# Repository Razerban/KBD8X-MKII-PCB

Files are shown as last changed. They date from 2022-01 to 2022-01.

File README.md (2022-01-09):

# KBD8X-MKII-PCB
This is a portable version of the [KBD8X MKII Project open sourced by Ai03](https://github.com/ai03-2725/KBD8X-MKII-PCB) used in the [KBD8X MKII by KBDfans](https://kbdfans.com/collections/kbd8x-mkii/products/coming-soon-kbd8x-mkii-custom-mechanical-keyboard-kit).

Please verify the conditions of the [license](https://github.com/ai03-2725/KBD8X-MKII-PCB/blob/master/LICENSE) before using.

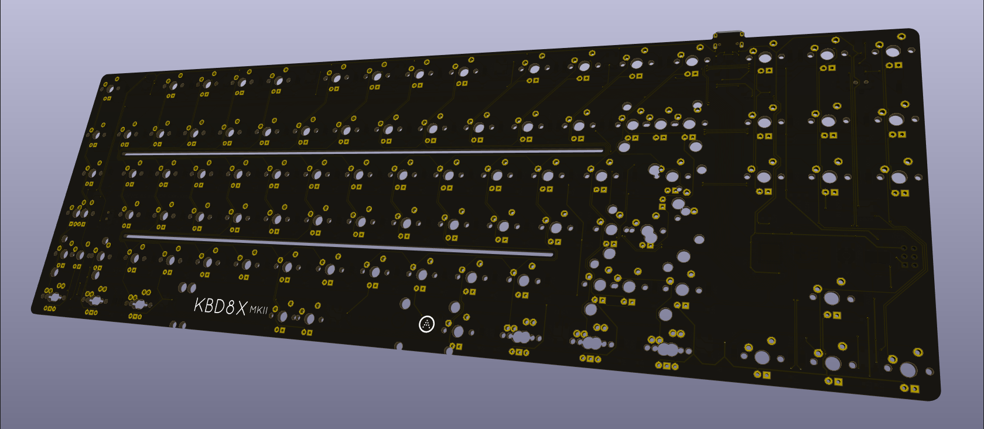
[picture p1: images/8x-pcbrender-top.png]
render

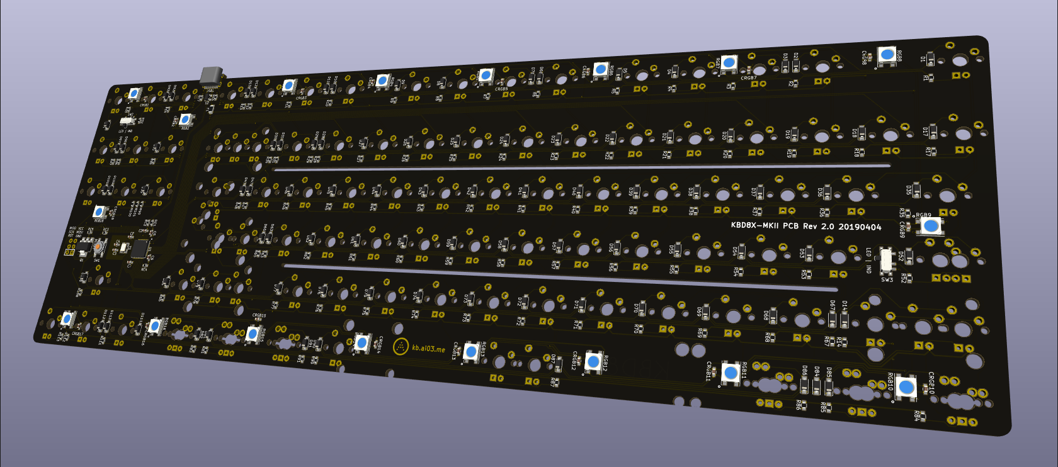
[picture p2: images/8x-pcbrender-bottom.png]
render


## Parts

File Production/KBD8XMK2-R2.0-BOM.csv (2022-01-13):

Comment | Designator | Footprint | LCSC
Crystal 3225 3.2x2.5mm 16MHz | Y1 | Crystal_SMD_3225-4pin_3.2x2.5mm | C13738
Capacitor Ceramic 0603 ≥15V 0.1uF | C6,C7,C8,CRGB1,CRGB10,CRGB11,CRGB12,CRGB13,CRGB14,CRGB15,CRGB16,CRGB17,CRGB18,CRGB2,CRGB3,CRGB4,CRGB5,CRGB6,CRGB7,CRGB8,CRGB9 | C_0603 | C14663
NPN transistor DSS60601MZ4-13 | Q1 | SOT-223-3_TabPin2 | C150451
Capacitor Ceramic 0603 ≥15V 1uF | C2 | C_0603 | C15849
Capacitor Ceramic 0603 ≥15V 22pF | C3,C4 | C_0603 | C1653
USB Type-C Connector HRO-TYPE-C-31-M-12 | USB1 | HRO-TYPE-C-31-M-12-Assembly | C165948
Resistor 0603 1k | R1,R10,R100,R101,R108,R11,R111,R112,R113,R12,R13,R14,R16,R17,R18,R19,R2,R20,R21,R22,R23,R24,R25,R26,R27,R28,R29,R3,R30,R31,R32,R33,R35,R36,R37,R38,R39,R4,R40,R41,R42,R43,R44,R45,R46,R47,R48,R5,R52,R53,R54,R55,R56,R57,R58,R59,R6,R60,R61,R62,R63,R65,R66,R67,R68,R69,R7,R70,R71,R72,R73,R74,R75,R76,R77,R78,R8,R81,R82,R84,R85,R86,R87,R9,R90,R91,R95,R96,R97,R99,RC4 | R_0603 | C21190
Diode SOD-323 | D1,D10,D100,D101,D108,D11,D111,D112,D113,D12,D13,D14,D17,D18,D19,D2,D20,D21,D22,D23,D24,D25,D26,D27,D28,D29,D3,D30,D31,D35,D36,D37,D38,D39,D4,D40,D41,D42,D43,D44,D45,D46,D47,D48,D5,D52,D53,D54,D55,D56,D57,D58,D59,D6,D60,D61,D62,D63,D65,D66,D67,D68,D69,D7,D70,D71,D72,D73,D74,D75,D76,D77,D78,D8,D81,D82,D84,D85,D86,D87,D9,D90,D91,D92,D93,D94,D95,D96,D97,D99 | D_SOD-123 | C2128
Switch SPDT PCM12 | SW2,SW3 | SW_SPDT_PCM12 | C221841
Resistor 0603 1.5k | RC5 | R_0603 | C22843
Resistor 0603 22 | RC1,RC2 | R_0603 | C23345
Resistor 0603 5k1 | RC6,RC7 | R_0603 | C23186
Resistor 0603 10k | RC3 | R_0603 | C25804
Polyfuse 1206 500mA Hold 1A Trip ≥15V | F1 | Fuse_SMD1206_Wave | C261952
RGB LED WS2812B 5050 | RGB1,RGB10,RGB11,RGB12,RGB13,RGB14,RGB15,RGB16,RGB17,RGB18,RGB2,RGB3,RGB4,RGB5,RGB6,RGB7,RGB8,RGB9 | LED_WS2812B-PLCC4 | C2761795
ESD Protection IC PRTR5V0U2X 215 | U2 | SOT143B | C2827688
Push button 5.2 x 5.2mm | SW1 | SKQG-1155865 | C318884
Microship ATmega32U4-MU | U1 | QFN-44-1EP_7x7mm_Pitch0.5mm | C45874
Capacitor Ceramic 0603 ≥15V 10uF | C5 | C_0603 | C96446

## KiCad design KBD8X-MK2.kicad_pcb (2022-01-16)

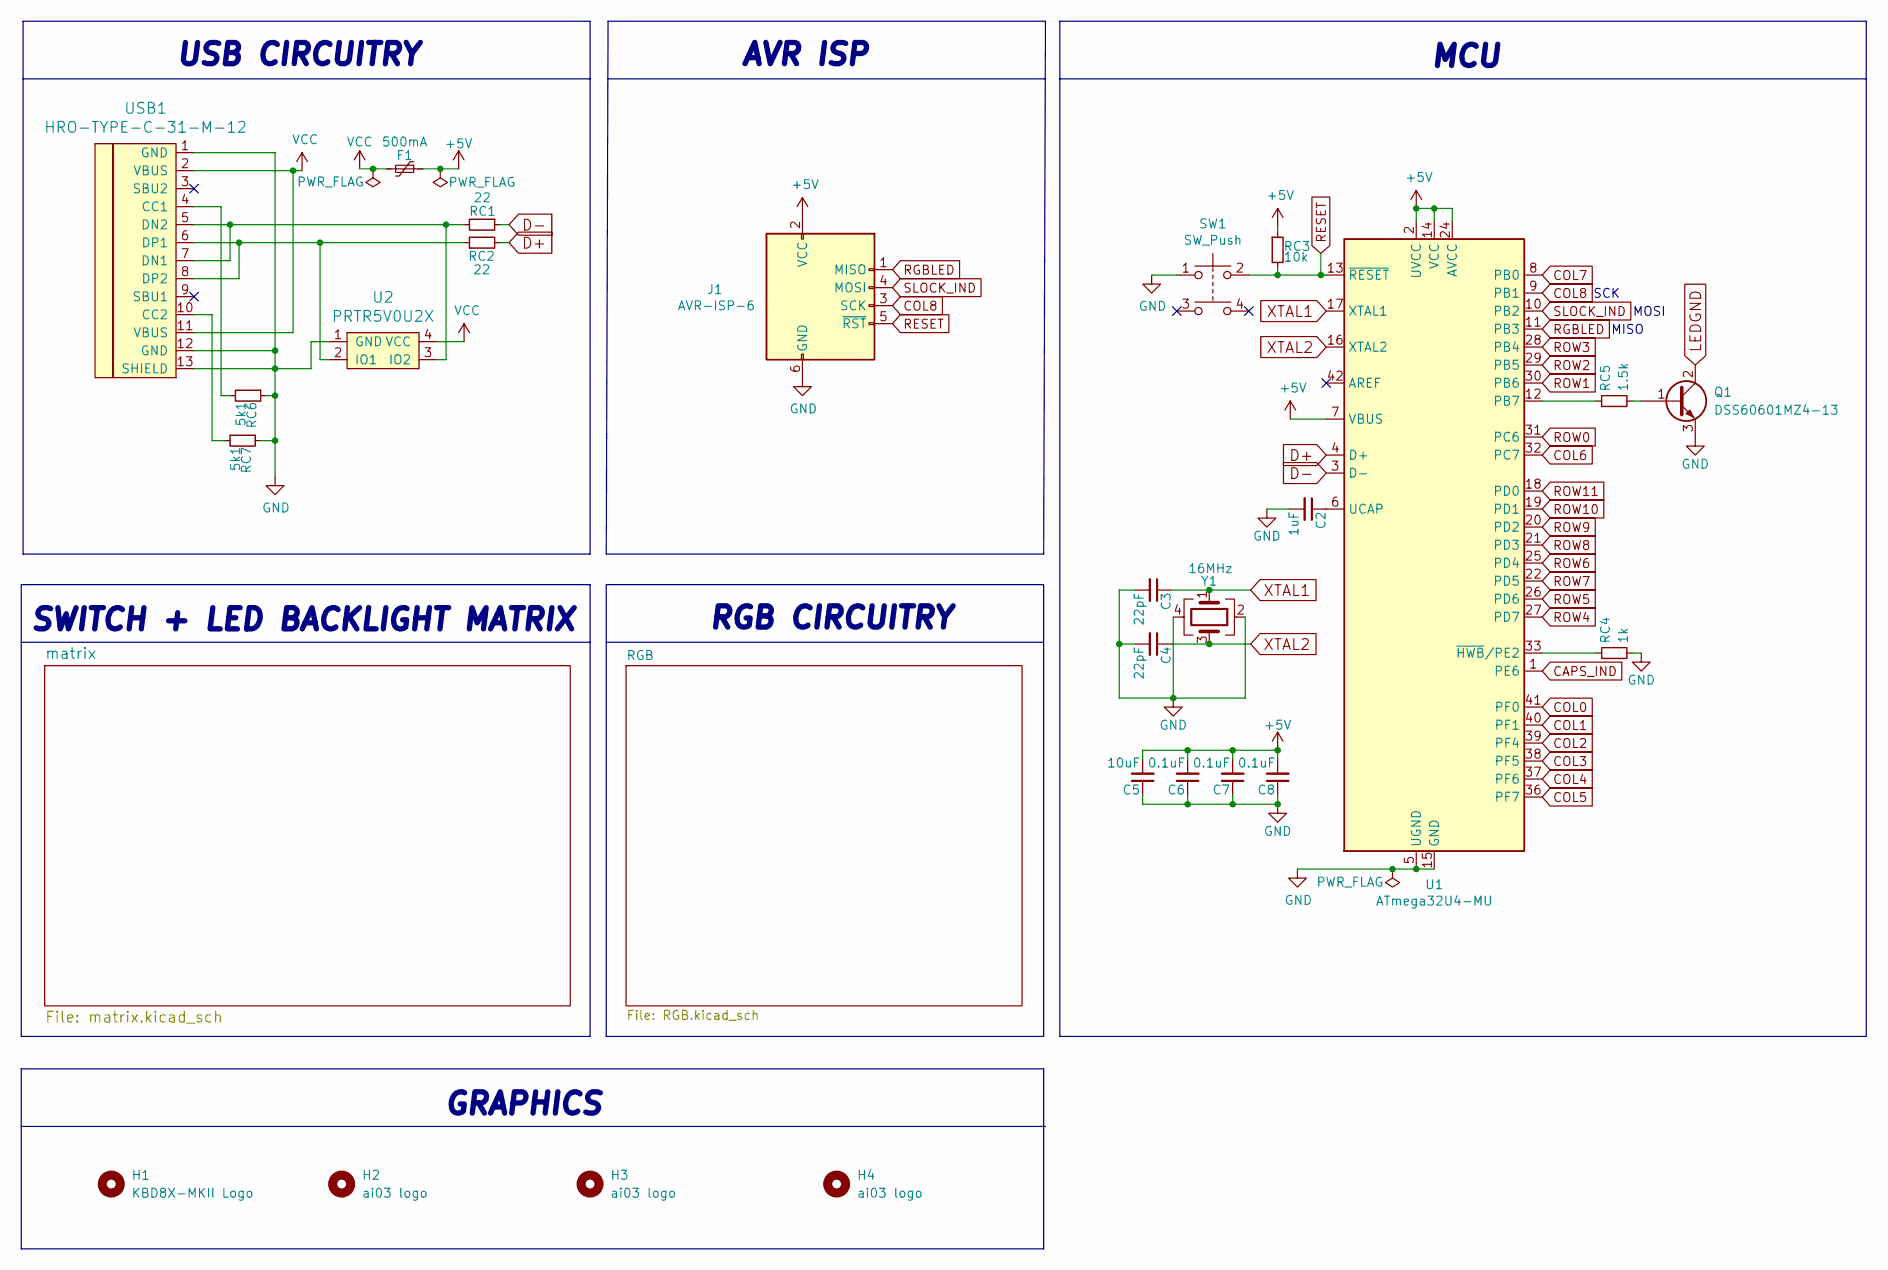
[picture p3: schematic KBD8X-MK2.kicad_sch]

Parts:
C2: 1uF; C_0603
C3, C4: 22pF; C_0603
C5: 10uF; C_0603
C6, C7, C8: 0.1uF; C_0603
F1: 500mA; Fuse_1206_3216Metric
H1: KBD8X-MKII Logo; kbd8x-logo
H2: ai03 logo; ai-ring-6mm-FancyAss
H3: ai03 logo; ai-ring-6mm-FancyAss-Mask
H4: ai03 logo; ai-ring-6mm
J1: AVR-ISP-6; Reset_Pretty-Mask
Q1: DSS60601MZ4-13; SOT-223-3_TabPin2
RC1, RC2: 22; R_0603
RC3: 10k; R_0603
RC4: 1k; R_0603
RC5: 1.5k; R_0603
RC6, RC7: 5k1; R_0603
SW1: SW_Push; SKQG-1155865
U1: ATmega32U4-MU; QFN-44-1EP_7x7mm_P0.5mm_EP5.2x5.2mm
U2: PRTR5V0U2X; SOT143B
USB1: HRO-TYPE-C-31-M-12; HRO-TYPE-C-31-M-12-Assembly
Y1: 16MHz; Crystal_SMD_3225-4pin_3.2x2.5mm

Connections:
+5V: C5.2, C6.2, C7.2, C8.2, F1.1, J1.2 (VCC), RC3.1, U1.2 (UVCC), U1.7 (VBUS), U1.14 (VCC), U1.24 (AVCC), U1.34 (VCC), U1.44 (AVCC); also elsewhere on the board
CAPS_IND: U1.1 (PE6); also elsewhere on the board
COL0: U1.41 (PF0); also elsewhere on the board
COL1: U1.40 (PF1); also elsewhere on the board
COL2: U1.39 (PF4); also elsewhere on the board
COL3: U1.38 (PF5); also elsewhere on the board
COL4: U1.37 (PF6); also elsewhere on the board
COL5: U1.36 (PF7); also elsewhere on the board
COL6: U1.32 (PC7); also elsewhere on the board
COL7: U1.8 (PB0); also elsewhere on the board
COL8: J1.3 (SCK), U1.9 (PB1); also elsewhere on the board
D+: RC2.2, U1.4 (D+)
D-: RC1.1, U1.3 (D-)
GND: C2.2, C3.2, C4.2, C5.1, C6.1, C7.1, C8.1, J1.6 (GND), Q1.3 (E), RC4.2, RC6.1, RC7.1, SW1.1, U1.5 (UGND), U1.15 (GND), U1.23 (GND), U1.35 (GND), U1.43 (GND), U1.45 (GND), U2.1 (GND), USB1.1 (GND), USB1.12 (GND), USB1.13 (SHIELD), Y1.2, Y1.4; also elsewhere on the board
LEDGND: Q1.2 (C); also elsewhere on the board
unnamed: C2.1, U1.6 (UCAP)
unnamed: Q1.1 (B), RC5.2
unnamed: RC1.2, U2.3 (IO2), USB1.5 (DN2), USB1.7 (DN1)
unnamed: RC2.1, U2.2 (IO1), USB1.6 (DP1), USB1.8 (DP2)
unnamed: RC4.1, U1.33 (~HWB/PE2)
unnamed: RC5.1, U1.12 (PB7)
unnamed: RC6.2, USB1.4 (CC1)
unnamed: RC7.2, USB1.10 (CC2)
RESET: J1.5 (~RST), RC3.2, SW1.2, U1.13 (~RESET)
RGBLED: J1.1 (MISO), U1.11 (PB3); also elsewhere on the board
ROW0: U1.31 (PC6); also elsewhere on the board
ROW1: U1.30 (PB6); also elsewhere on the board
ROW2: U1.29 (PB5); also elsewhere on the board
ROW3: U1.28 (PB4); also elsewhere on the board
ROW4: U1.27 (PD7); also elsewhere on the board
ROW5: U1.26 (PD6); also elsewhere on the board
ROW6: U1.25 (PD4); also elsewhere on the board
ROW7: U1.22 (PD5); also elsewhere on the board
ROW8: U1.21 (PD3); also elsewhere on the board
ROW9: U1.20 (PD2); also elsewhere on the board
ROW10: U1.19 (PD1); also elsewhere on the board
ROW11: U1.18 (PD0); also elsewhere on the board
SLOCK_IND: J1.4 (MOSI), U1.10 (PB2); also elsewhere on the board
VCC: F1.2, U2.4 (VCC), USB1.2 (VBUS), USB1.11 (VBUS)
XTAL1: C3.1, U1.17 (XTAL1), Y1.1
XTAL2: C4.1, U1.16 (XTAL2), Y1.3

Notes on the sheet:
SCK
MCU
RGB CIRCUITRY
USB CIRCUITRY
GRAPHICS
AVR ISP
MOSI
SWITCH + LED BACKLIGHT MATRIX
MISO

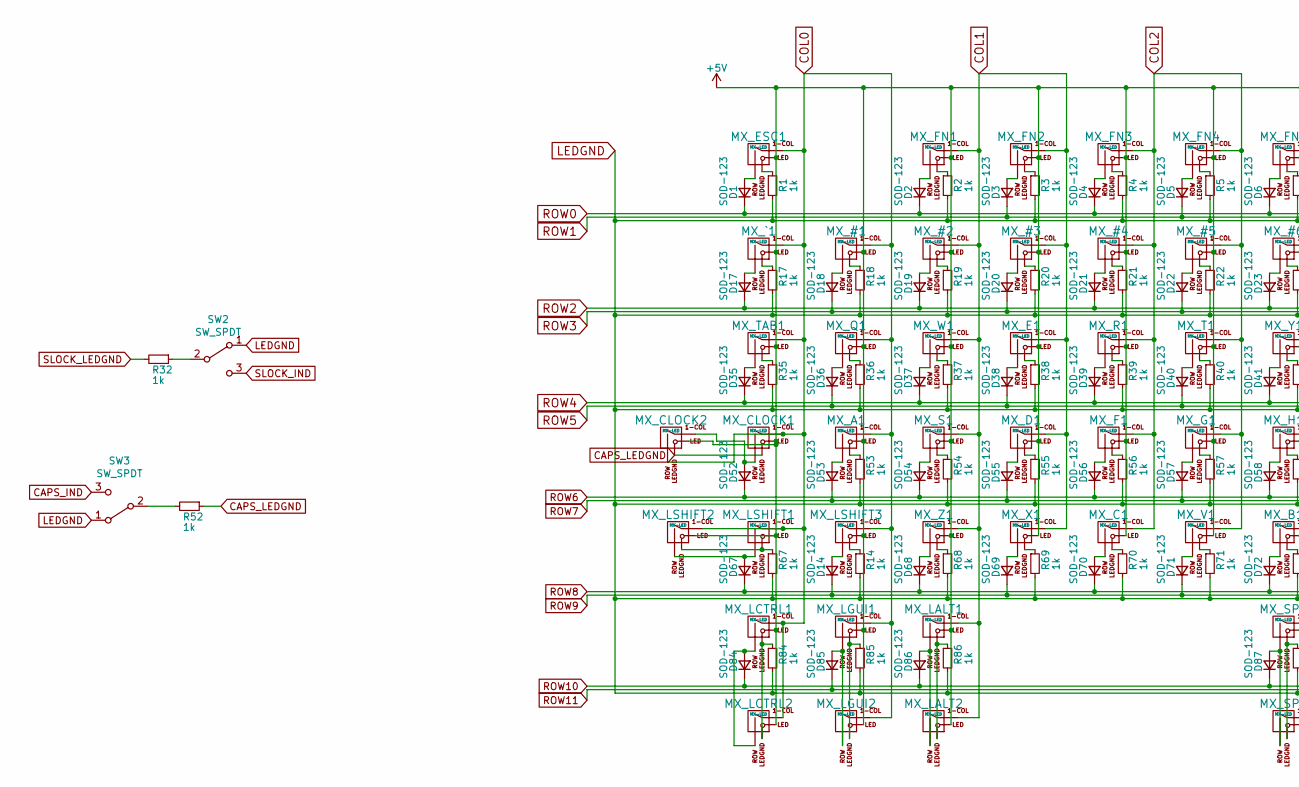
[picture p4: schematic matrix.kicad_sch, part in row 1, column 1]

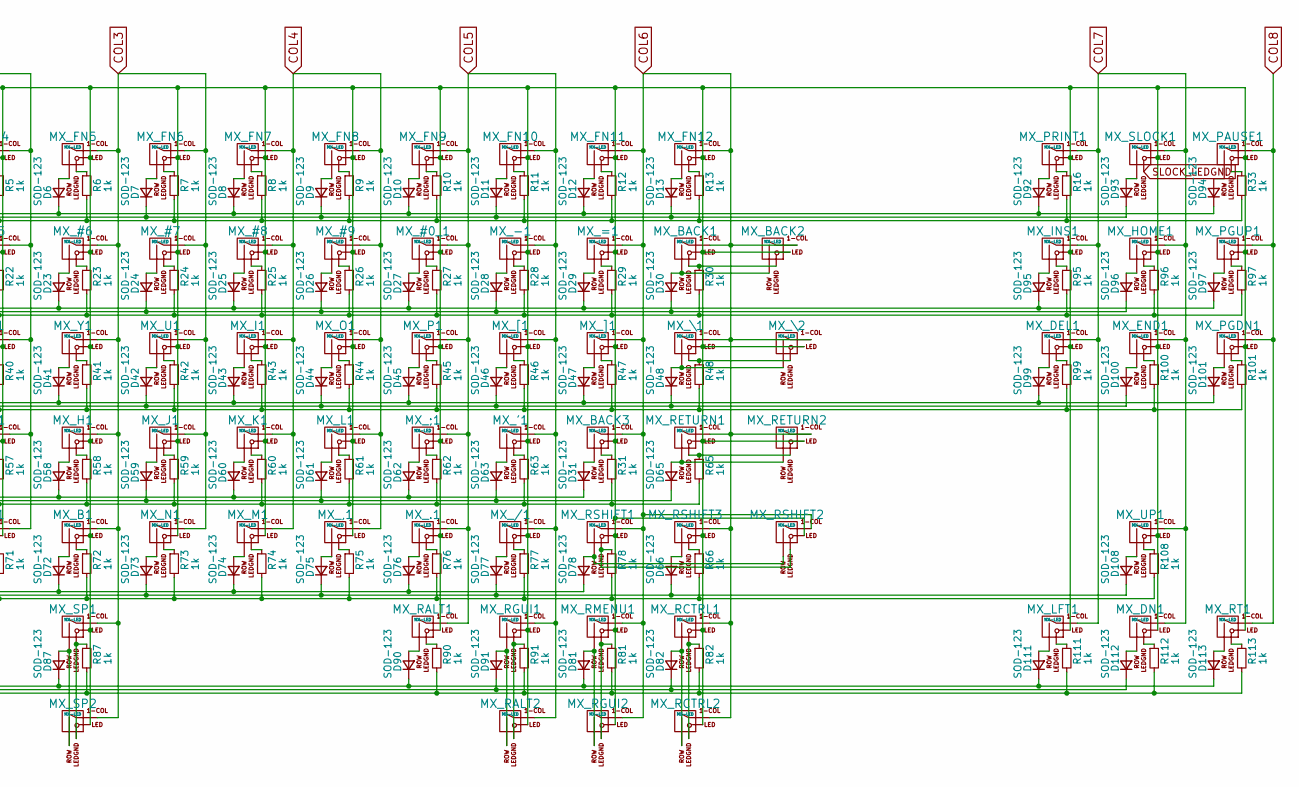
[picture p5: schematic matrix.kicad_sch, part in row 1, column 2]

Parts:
D1, D2, D3, D4, D5, D6, D7, D8, D9, D10, D11, D12, D13, D14, D17, D18, D19, D20, D21, D22, D23, D24, D25, D26, D27, D28, D29, D30, D31, D35, D36, D37, D38, D39, D40, D41, D42, D43, D44, D45, D46, D47, D48, D52, D53, D54, D55, D56, D57, D58, D59, D60, D61, D62, D63, D65, D66, D67, D68, D69, D70, D71, D72, D73, D74, D75, D76, D77, D78, D81, D82, D84, D85, D86, D87, D90, D91, D92, D93, D94, D95, D96, D97, D99, D100, D101, D108, D111, D112, D113: SOD-123; D_SOD-123
MX_#0_1, MX_#1, MX_#2, MX_#3, MX_#4, MX_#5, MX_#6, MX_#7, MX_#8, MX_#9: MX-LED; MXOnly-1U
MX_'1: MX-LED; MXOnly-1U
MX_,1: MX-LED; MXOnly-1U
MX_-1: MX-LED; MXOnly-1U
MX_.1: MX-LED; MXOnly-1U
MX_/1: MX-LED; MXOnly-1U
MX_;1: MX-LED; MXOnly-1U
MX_=1: MX-LED; MXOnly-1U
MX_A1: MX-LED; MXOnly-1U
MX_B1: MX-LED; MXOnly-1U
MX_BACK1: MX-LED; MXOnly-2U
MX_BACK2, MX_BACK3: MX-LED; MXOnly-1U
MX_C1: MX-LED; MXOnly-1U
MX_CLOCK1: MX-LED; MXOnly-1.75U
MX_CLOCK2: MX-LED; MXOnly-1.25U-FLIPPED
MX_D1: MX-LED; MXOnly-1U
MX_DEL1: MX-LED; MXOnly-1U
MX_DN1: MX-LED; MXOnly-1U
MX_E1: MX-LED; MXOnly-1U
MX_END1: MX-LED; MXOnly-1U
MX_ESC1: MX-LED; MXOnly-1U
MX_F1: MX-LED; MXOnly-1U
MX_FN1, MX_FN2, MX_FN3, MX_FN4, MX_FN5, MX_FN6, MX_FN7, MX_FN8, MX_FN9, MX_FN10, MX_FN11, MX_FN12: MX-LED; MXOnly-1U
MX_G1: MX-LED; MXOnly-1U
MX_H1: MX-LED; MXOnly-1U
MX_HOME1: MX-LED; MXOnly-1U
MX_I1: MX-LED; MXOnly-1U
MX_INS1: MX-LED; MXOnly-1U
MX_J1: MX-LED; MXOnly-1U
MX_K1: MX-LED; MXOnly-1U
MX_L1: MX-LED; MXOnly-1U
MX_LALT1: MX-LED; MXOnly-1.25U
MX_LALT2: MX-LED; MXOnly-1.5U-FLIPPED
MX_LCTRL1: MX-LED; MXOnly-1.25U
MX_LCTRL2: MX-LED; MXOnly-1.5U-FLIPPED
MX_LFT1: MX-LED; MXOnly-1U
MX_LGUI1: MX-LED; MXOnly-1.25U
MX_LGUI2: MX-LED; MXOnly-1U-FLIPPED
MX_LSHIFT1: MX-LED; MXOnly-2.25U
MX_LSHIFT2: MX-LED; MXOnly-1.25U
MX_LSHIFT3: MX-LED; MXOnly-1U
MX_M1: MX-LED; MXOnly-1U
MX_N1: MX-LED; MXOnly-1U
MX_O1: MX-LED; MXOnly-1U
MX_P1: MX-LED; MXOnly-1U
MX_PAUSE1: MX-LED; MXOnly-1U
MX_PGDN1: MX-LED; MXOnly-1U
MX_PGUP1: MX-LED; MXOnly-1U
MX_PRINT1: MX-LED; MXOnly-1U
MX_Q1: MX-LED; MXOnly-1U
MX_R1: MX-LED; MXOnly-1U
MX_RALT1: MX-LED; MXOnly-1.25U
MX_RALT2: MX-LED; MXOnly-1.5U
MX_RCTRL1: MX-LED; MXOnly-1.25U-FLIPPED
MX_RCTRL2: MX-LED; MXOnly-1.5U
MX_RETURN1: MX-LED; MXOnly-2.25U
MX_RETURN2: MX-LED; MXOnly-ISO-ROTATED-ReversedStabilizers
MX_RGUI1: MX-LED; MXOnly-1.25U-FLIPPED
MX_RGUI2: MX-LED; MXOnly-1U
MX_RMENU1: MX-LED; MXOnly-1.25U-FLIPPED
MX_RSHIFT1: MX-LED; MXOnly-2.75U
MX_RSHIFT2: MX-LED; MXOnly-1.75U
MX_RSHIFT3: MX-LED; MXOnly-1U
MX_RT1: MX-LED; MXOnly-1U
MX_S1: MX-LED; MXOnly-1U
MX_SLOCK1: MX-LED; MXOnly-1U
MX_SP1: MX-LED; MXOnly-6.25U-ReversedStabilizers
MX_SP2: MX-LED; MXOnly-7U-ReversedStabilizers
MX_T1: MX-LED; MXOnly-1U
MX_TAB1: MX-LED; MXOnly-1.5U
MX_U1: MX-LED; MXOnly-1U
MX_UP1: MX-LED; MXOnly-1U
MX_V1: MX-LED; MXOnly-1U
MX_W1: MX-LED; MXOnly-1U
MX_X1: MX-LED; MXOnly-1U
MX_Y1: MX-LED; MXOnly-1U
MX_Z1: MX-LED; MXOnly-1U
MX_[1: MX-LED; MXOnly-1U
MX_\1: MX-LED; MXOnly-1.5U
MX_\2: MX-LED; MXOnly-1U
MX_]1: MX-LED; MXOnly-1U
MX_`1: MX-LED; MXOnly-1U
R1, R2, R3, R4, R5, R6, R7, R8, R9, R10, R11, R12, R13, R14, R16, R17, R18, R19, R20, R21, R22, R23, R24, R25, R26, R27, R28, R29, R30, R31, R32, R33, R35, R36, R37, R38, R39, R40, R41, R42, R43, R44, R45, R46, R47, R48, R52, R53, R54, R55, R56, R57, R58, R59, R60, R61, R62, R63, R65, R66, R67, R68, R69, R70, R71, R72, R73, R74, R75, R76, R77, R78, R81, R82, R84, R85, R86, R87, R90, R91, R95, R96, R97, R99, R100, R101, R108, R111, R112, R113: 1k; R_0603
SW2, SW3: SW_SPDT; SW_SPDT_PCM12

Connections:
+5V: MX_#0_1.3 (LED), MX_#1.3 (LED), MX_#2.3 (LED), MX_#3.3 (LED), MX_#4.3 (LED), MX_#5.3 (LED), MX_#6.3 (LED), MX_#7.3 (LED), MX_#8.3 (LED), MX_#9.3 (LED), MX_'1.3 (LED), MX_,1.3 (LED), MX_-1.3 (LED), MX_.1.3 (LED), MX_/1.3 (LED), MX_;1.3 (LED), MX_=1.3 (LED), MX_A1.3 (LED), MX_B1.3 (LED), MX_BACK1.3 (LED), MX_BACK2.3 (LED), MX_BACK3.3 (LED), MX_C1.3 (LED), MX_CLOCK1.3 (LED), MX_CLOCK2.3 (LED), MX_D1.3 (LED), MX_DEL1.3 (LED), MX_DN1.3 (LED), MX_E1.3 (LED), MX_END1.3 (LED), MX_ESC1.3 (LED), MX_F1.3 (LED), MX_FN1.3 (LED), MX_FN2.3 (LED), MX_FN3.3 (LED), MX_FN4.3 (LED), MX_FN5.3 (LED), MX_FN6.3 (LED), MX_FN7.3 (LED), MX_FN8.3 (LED), MX_FN9.3 (LED), MX_FN10.3 (LED), MX_FN11.3 (LED), MX_FN12.3 (LED), MX_G1.3 (LED), MX_H1.3 (LED), MX_HOME1.3 (LED), MX_I1.3 (LED), MX_INS1.3 (LED), MX_J1.3 (LED), MX_K1.3 (LED), MX_L1.3 (LED), MX_LALT1.3 (LED), MX_LALT2.3 (LED), MX_LCTRL1.3 (LED), MX_LCTRL2.3 (LED), MX_LFT1.3 (LED), MX_LGUI1.3 (LED), MX_LGUI2.3 (LED), MX_LSHIFT1.3 (LED), MX_LSHIFT2.3 (LED), MX_LSHIFT3.3 (LED), MX_M1.3 (LED), MX_N1.3 (LED), MX_O1.3 (LED), MX_P1.3 (LED), MX_PAUSE1.3 (LED), MX_PGDN1.3 (LED), MX_PGUP1.3 (LED), MX_PRINT1.3 (LED), MX_Q1.3 (LED), MX_R1.3 (LED), MX_RALT1.3 (LED), MX_RALT2.3 (LED), MX_RCTRL1.3 (LED), MX_RCTRL2.3 (LED), MX_RETURN1.3 (LED), MX_RETURN2.3 (LED), MX_RGUI1.3 (LED), MX_RGUI2.3 (LED), MX_RMENU1.3 (LED), MX_RSHIFT1.3 (LED), MX_RSHIFT2.3 (LED), MX_RSHIFT3.3 (LED), MX_RT1.3 (LED), MX_S1.3 (LED), MX_SLOCK1.3 (LED), MX_SP1.3 (LED), MX_SP2.3 (LED), MX_T1.3 (LED), MX_TAB1.3 (LED), MX_U1.3 (LED), MX_UP1.3 (LED), MX_V1.3 (LED), MX_W1.3 (LED), MX_X1.3 (LED), MX_Y1.3 (LED), MX_Z1.3 (LED), MX_[1.3 (LED), MX_\1.3 (LED), MX_\2.3 (LED), MX_]1.3 (LED), MX_`1.3 (LED); also elsewhere on the board
CAPS_IND: SW3.3 (C); also elsewhere on the board
CAPS_LEDGND: MX_CLOCK1.4 (LEDGND), MX_CLOCK2.4 (LEDGND), R52.1
COL0: MX_#1.1 (COL), MX_A1.1 (COL), MX_CLOCK1.1 (COL), MX_CLOCK2.2 (ROW), MX_ESC1.1 (COL), MX_LCTRL1.1 (COL), MX_LCTRL2.1 (COL), MX_LGUI1.1 (COL), MX_LGUI2.1 (COL), MX_LSHIFT1.1 (COL), MX_LSHIFT2.1 (COL), MX_LSHIFT3.1 (COL), MX_Q1.1 (COL), MX_TAB1.1 (COL), MX_`1.1 (COL); also elsewhere on the board
COL1: MX_#2.1 (COL), MX_#3.1 (COL), MX_D1.1 (COL), MX_E1.1 (COL), MX_FN1.1 (COL), MX_FN2.1 (COL), MX_LALT1.1 (COL), MX_LALT2.1 (COL), MX_S1.1 (COL), MX_W1.1 (COL), MX_X1.1 (COL), MX_Z1.1 (COL); also elsewhere on the board
COL2: MX_#4.1 (COL), MX_#5.1 (COL), MX_C1.1 (COL), MX_F1.1 (COL), MX_FN3.1 (COL), MX_FN4.1 (COL), MX_G1.1 (COL), MX_R1.1 (COL), MX_T1.1 (COL), MX_V1.1 (COL); also elsewhere on the board
COL3: MX_#6.1 (COL), MX_#7.1 (COL), MX_B1.1 (COL), MX_FN5.1 (COL), MX_FN6.1 (COL), MX_H1.1 (COL), MX_J1.1 (COL), MX_N1.1 (COL), MX_SP1.1 (COL), MX_SP2.1 (COL), MX_U1.1 (COL), MX_Y1.1 (COL); also elsewhere on the board
COL4: MX_#8.1 (COL), MX_#9.1 (COL), MX_,1.1 (COL), MX_FN7.1 (COL), MX_FN8.1 (COL), MX_I1.1 (COL), MX_K1.1 (COL), MX_L1.1 (COL), MX_M1.1 (COL), MX_O1.1 (COL); also elsewhere on the board
COL5: MX_#0_1.1 (COL), MX_'1.1 (COL), MX_-1.1 (COL), MX_.1.1 (COL), MX_/1.1 (COL), MX_;1.1 (COL), MX_FN9.1 (COL), MX_FN10.1 (COL), MX_P1.1 (COL), MX_RALT1.1 (COL), MX_RALT2.1 (COL), MX_RGUI1.1 (COL), MX_[1.1 (COL); also elsewhere on the board
COL6: MX_=1.1 (COL), MX_BACK1.1 (COL), MX_BACK2.1 (COL), MX_BACK3.1 (COL), MX_FN11.1 (COL), MX_FN12.1 (COL), MX_RCTRL1.1 (COL), MX_RCTRL2.1 (COL), MX_RETURN1.1 (COL), MX_RETURN2.1 (COL), MX_RGUI2.1 (COL), MX_RMENU1.1 (COL), MX_RSHIFT1.1 (COL), MX_RSHIFT2.1 (COL), MX_RSHIFT3.1 (COL), MX_\1.1 (COL), MX_\2.1 (COL), MX_]1.1 (COL); also elsewhere on the board
COL7: MX_DEL1.1 (COL), MX_DN1.1 (COL), MX_END1.1 (COL), MX_HOME1.1 (COL), MX_INS1.1 (COL), MX_LFT1.1 (COL), MX_PRINT1.1 (COL), MX_SLOCK1.1 (COL), MX_UP1.1 (COL); also elsewhere on the board
COL8: MX_PAUSE1.1 (COL), MX_PGDN1.1 (COL), MX_PGUP1.1 (COL), MX_RT1.1 (COL); also elsewhere on the board
LEDGND: R1.2, R2.2, R3.2, R4.2, R5.2, R6.2, R7.2, R8.2, R9.2, R10.2, R11.2, R12.2, R13.2, R14.2, R16.2, R17.2, R18.2, R19.2, R20.2, R21.2, R22.2, R23.2, R24.2, R25.2, R26.2, R27.2, R28.2, R29.2, R30.2, R31.2, R33.2, R35.2, R36.2, R37.2, R38.2, R39.2, R40.2, R41.2, R42.2, R43.2, R44.2, R45.2, R46.2, R47.2, R48.2, R53.2, R54.2, R55.2, R56.2, R57.2, R58.2, R59.2, R60.2, R61.2, R62.2, R63.2, R65.2, R66.2, R67.2, R68.2, R69.2, R70.2, R71.2, R72.2, R73.2, R74.2, R75.2, R76.2, R77.2, R78.2, R81.2, R82.2, R84.2, R85.2, R86.2, R87.2, R90.2, R91.2, R95.2, R96.2, R97.2, R99.2, R100.2, R101.2, R108.2, R111.2, R112.2, R113.2, SW2.1 (A), SW3.1 (A); also elsewhere on the board
unnamed: D1.2 (A), MX_ESC1.2 (ROW)
unnamed: D2.2 (A), MX_FN1.2 (ROW)
unnamed: D3.2 (A), MX_FN2.2 (ROW)
unnamed: D4.2 (A), MX_FN3.2 (ROW)
unnamed: D5.2 (A), MX_FN4.2 (ROW)
unnamed: D6.2 (A), MX_FN5.2 (ROW)
unnamed: D7.2 (A), MX_FN6.2 (ROW)
unnamed: D8.2 (A), MX_FN7.2 (ROW)
unnamed: D9.2 (A), MX_FN8.2 (ROW)
unnamed: D10.2 (A), MX_FN9.2 (ROW)
unnamed: D11.2 (A), MX_FN10.2 (ROW)
unnamed: D12.2 (A), MX_FN11.2 (ROW)
unnamed: D13.2 (A), MX_FN12.2 (ROW)
unnamed: D14.2 (A), MX_LSHIFT3.2 (ROW)
unnamed: D17.2 (A), MX_`1.2 (ROW)
unnamed: D18.2 (A), MX_#1.2 (ROW)
unnamed: D19.2 (A), MX_#2.2 (ROW)
unnamed: D20.2 (A), MX_#3.2 (ROW)
unnamed: D21.2 (A), MX_#4.2 (ROW)
unnamed: D22.2 (A), MX_#5.2 (ROW)
unnamed: D23.2 (A), MX_#6.2 (ROW)
unnamed: D24.2 (A), MX_#7.2 (ROW)
unnamed: D25.2 (A), MX_#8.2 (ROW)
unnamed: D26.2 (A), MX_#9.2 (ROW)
unnamed: D27.2 (A), MX_#0_1.2 (ROW)
unnamed: D28.2 (A), MX_-1.2 (ROW)
unnamed: D29.2 (A), MX_=1.2 (ROW)
unnamed: D30.2 (A), MX_BACK1.2 (ROW), MX_BACK2.2 (ROW)
unnamed: D31.2 (A), MX_BACK3.2 (ROW)
unnamed: D35.2 (A), MX_TAB1.2 (ROW)
unnamed: D36.2 (A), MX_Q1.2 (ROW)
unnamed: D37.2 (A), MX_W1.2 (ROW)
unnamed: D38.2 (A), MX_E1.2 (ROW)
unnamed: D39.2 (A), MX_R1.2 (ROW)
unnamed: D40.2 (A), MX_T1.2 (ROW)
unnamed: D41.2 (A), MX_Y1.2 (ROW)
unnamed: D42.2 (A), MX_U1.2 (ROW)
unnamed: D43.2 (A), MX_I1.2 (ROW)
unnamed: D44.2 (A), MX_O1.2 (ROW)
unnamed: D45.2 (A), MX_P1.2 (ROW)
unnamed: D46.2 (A), MX_[1.2 (ROW)
unnamed: D47.2 (A), MX_]1.2 (ROW)
unnamed: D48.2 (A), MX_\1.2 (ROW), MX_\2.2 (ROW)
unnamed: D52.2 (A), MX_CLOCK1.2 (ROW), MX_CLOCK2.1 (COL)
unnamed: D53.2 (A), MX_A1.2 (ROW)
unnamed: D54.2 (A), MX_S1.2 (ROW)
unnamed: D55.2 (A), MX_D1.2 (ROW)
unnamed: D56.2 (A), MX_F1.2 (ROW)
unnamed: D57.2 (A), MX_G1.2 (ROW)
unnamed: D58.2 (A), MX_H1.2 (ROW)
unnamed: D59.2 (A), MX_J1.2 (ROW)
unnamed: D60.2 (A), MX_K1.2 (ROW)
unnamed: D61.2 (A), MX_L1.2 (ROW)
unnamed: D62.2 (A), MX_;1.2 (ROW)
unnamed: D63.2 (A), MX_'1.2 (ROW)
unnamed: D65.2 (A), MX_RETURN1.2 (ROW), MX_RETURN2.2 (ROW)
unnamed: D66.2 (A), MX_RSHIFT3.2 (ROW)
unnamed: D67.2 (A), MX_LSHIFT1.2 (ROW), MX_LSHIFT2.2 (ROW)
unnamed: D68.2 (A), MX_Z1.2 (ROW)
unnamed: D69.2 (A), MX_X1.2 (ROW)
unnamed: D70.2 (A), MX_C1.2 (ROW)
unnamed: D71.2 (A), MX_V1.2 (ROW)
unnamed: D72.2 (A), MX_B1.2 (ROW)
unnamed: D73.2 (A), MX_N1.2 (ROW)
unnamed: D74.2 (A), MX_M1.2 (ROW)
unnamed: D75.2 (A), MX_,1.2 (ROW)
unnamed: D76.2 (A), MX_.1.2 (ROW)
unnamed: D77.2 (A), MX_/1.2 (ROW)
unnamed: D78.2 (A), MX_RSHIFT1.2 (ROW), MX_RSHIFT2.2 (ROW)
unnamed: D81.2 (A), MX_RGUI2.2 (ROW), MX_RMENU1.2 (ROW)
unnamed: D82.2 (A), MX_RCTRL1.2 (ROW), MX_RCTRL2.2 (ROW)
unnamed: D84.2 (A), MX_LCTRL1.2 (ROW), MX_LCTRL2.2 (ROW)
unnamed: D85.2 (A), MX_LGUI1.2 (ROW), MX_LGUI2.2 (ROW)
unnamed: D86.2 (A), MX_LALT1.2 (ROW), MX_LALT2.2 (ROW)
unnamed: D87.2 (A), MX_SP1.2 (ROW), MX_SP2.2 (ROW)
unnamed: D90.2 (A), MX_RALT1.2 (ROW)
unnamed: D91.2 (A), MX_RALT2.2 (ROW), MX_RGUI1.2 (ROW)
unnamed: D92.2 (A), MX_PRINT1.2 (ROW)
unnamed: D93.2 (A), MX_SLOCK1.2 (ROW)
unnamed: D94.2 (A), MX_PAUSE1.2 (ROW)
unnamed: D95.2 (A), MX_INS1.2 (ROW)
unnamed: D96.2 (A), MX_HOME1.2 (ROW)
unnamed: D97.2 (A), MX_PGUP1.2 (ROW)
unnamed: D99.2 (A), MX_DEL1.2 (ROW)
unnamed: D100.2 (A), MX_END1.2 (ROW)
unnamed: D101.2 (A), MX_PGDN1.2 (ROW)
unnamed: D108.2 (A), MX_UP1.2 (ROW)
unnamed: D111.2 (A), MX_LFT1.2 (ROW)
unnamed: D112.2 (A), MX_DN1.2 (ROW)
unnamed: D113.2 (A), MX_RT1.2 (ROW)
unnamed: MX_#0_1.4 (LEDGND), R27.1
unnamed: MX_#1.4 (LEDGND), R18.1
unnamed: MX_#2.4 (LEDGND), R19.1
unnamed: MX_#3.4 (LEDGND), R20.1
unnamed: MX_#4.4 (LEDGND), R21.1
unnamed: MX_#5.4 (LEDGND), R22.1
unnamed: MX_#6.4 (LEDGND), R23.1
unnamed: MX_#7.4 (LEDGND), R24.1
unnamed: MX_#8.4 (LEDGND), R25.1
unnamed: MX_#9.4 (LEDGND), R26.1
unnamed: MX_'1.4 (LEDGND), R63.1
unnamed: MX_,1.4 (LEDGND), R75.1
unnamed: MX_-1.4 (LEDGND), R28.1
unnamed: MX_.1.4 (LEDGND), R76.1
unnamed: MX_/1.4 (LEDGND), R77.1
unnamed: MX_;1.4 (LEDGND), R62.1
unnamed: MX_=1.4 (LEDGND), R29.1
unnamed: MX_A1.4 (LEDGND), R53.1
unnamed: MX_B1.4 (LEDGND), R72.1
unnamed: MX_BACK1.4 (LEDGND), MX_BACK2.4 (LEDGND), R30.1
unnamed: MX_BACK3.4 (LEDGND), R31.1
unnamed: MX_C1.4 (LEDGND), R70.1
unnamed: MX_D1.4 (LEDGND), R55.1
unnamed: MX_DEL1.4 (LEDGND), R99.1
unnamed: MX_DN1.4 (LEDGND), R112.1
unnamed: MX_E1.4 (LEDGND), R38.1
unnamed: MX_END1.4 (LEDGND), R100.1
unnamed: MX_ESC1.4 (LEDGND), R1.1
unnamed: MX_F1.4 (LEDGND), R56.1
unnamed: MX_FN1.4 (LEDGND), R2.1
unnamed: MX_FN2.4 (LEDGND), R3.1
unnamed: MX_FN3.4 (LEDGND), R4.1
unnamed: MX_FN4.4 (LEDGND), R5.1
unnamed: MX_FN5.4 (LEDGND), R6.1
unnamed: MX_FN6.4 (LEDGND), R7.1
unnamed: MX_FN7.4 (LEDGND), R8.1
unnamed: MX_FN8.4 (LEDGND), R9.1
unnamed: MX_FN9.4 (LEDGND), R10.1
unnamed: MX_FN10.4 (LEDGND), R11.1
unnamed: MX_FN11.4 (LEDGND), R12.1
unnamed: MX_FN12.4 (LEDGND), R13.1
unnamed: MX_G1.4 (LEDGND), R57.1
unnamed: MX_H1.4 (LEDGND), R58.1
unnamed: MX_HOME1.4 (LEDGND), R96.1
unnamed: MX_I1.4 (LEDGND), R43.1
unnamed: MX_INS1.4 (LEDGND), R95.1
unnamed: MX_J1.4 (LEDGND), R59.1
unnamed: MX_K1.4 (LEDGND), R60.1
unnamed: MX_L1.4 (LEDGND), R61.1
unnamed: MX_LALT1.4 (LEDGND), MX_LALT2.4 (LEDGND), R86.1
unnamed: MX_LCTRL1.4 (LEDGND), MX_LCTRL2.4 (LEDGND), R84.1
unnamed: MX_LFT1.4 (LEDGND), R111.1
unnamed: MX_LGUI1.4 (LEDGND), MX_LGUI2.4 (LEDGND), R85.1
unnamed: MX_LSHIFT1.4 (LEDGND), MX_LSHIFT2.4 (LEDGND), R67.1
unnamed: MX_LSHIFT3.4 (LEDGND), R14.1
unnamed: MX_M1.4 (LEDGND), R74.1
unnamed: MX_N1.4 (LEDGND), R73.1
unnamed: MX_O1.4 (LEDGND), R44.1
unnamed: MX_P1.4 (LEDGND), R45.1
unnamed: MX_PAUSE1.4 (LEDGND), R33.1
unnamed: MX_PGDN1.4 (LEDGND), R101.1
unnamed: MX_PGUP1.4 (LEDGND), R97.1
unnamed: MX_PRINT1.4 (LEDGND), R16.1
unnamed: MX_Q1.4 (LEDGND), R36.1
unnamed: MX_R1.4 (LEDGND), R39.1
unnamed: MX_RALT1.4 (LEDGND), R90.1
unnamed: MX_RALT2.4 (LEDGND), MX_RGUI1.4 (LEDGND), R91.1
unnamed: MX_RCTRL1.4 (LEDGND), MX_RCTRL2.4 (LEDGND), R82.1
unnamed: MX_RETURN1.4 (LEDGND), MX_RETURN2.4 (LEDGND), R65.1
unnamed: MX_RGUI2.4 (LEDGND), MX_RMENU1.4 (LEDGND), R81.1
unnamed: MX_RSHIFT1.4 (LEDGND), MX_RSHIFT2.4 (LEDGND), R78.1
unnamed: MX_RSHIFT3.4 (LEDGND), R66.1
unnamed: MX_RT1.4 (LEDGND), R113.1
unnamed: MX_S1.4 (LEDGND), R54.1
unnamed: MX_SP1.4 (LEDGND), MX_SP2.4 (LEDGND), R87.1
unnamed: MX_T1.4 (LEDGND), R40.1
unnamed: MX_TAB1.4 (LEDGND), R35.1
unnamed: MX_U1.4 (LEDGND), R42.1
unnamed: MX_UP1.4 (LEDGND), R108.1
unnamed: MX_V1.4 (LEDGND), R71.1
unnamed: MX_W1.4 (LEDGND), R37.1
unnamed: MX_X1.4 (LEDGND), R69.1
unnamed: MX_Y1.4 (LEDGND), R41.1
unnamed: MX_Z1.4 (LEDGND), R68.1
unnamed: MX_[1.4 (LEDGND), R46.1
unnamed: MX_\1.4 (LEDGND), MX_\2.4 (LEDGND), R48.1
unnamed: MX_]1.4 (LEDGND), R47.1
unnamed: MX_`1.4 (LEDGND), R17.1
unnamed: R32.1, SW2.2 (B)
unnamed: R52.2, SW3.2 (B)
ROW0: D1.1 (K), D2.1 (K), D4.1 (K), D6.1 (K), D8.1 (K), D10.1 (K), D12.1 (K), D92.1 (K), D94.1 (K); also elsewhere on the board
ROW1: D3.1 (K), D5.1 (K), D7.1 (K), D9.1 (K), D11.1 (K), D13.1 (K), D93.1 (K); also elsewhere on the board
ROW2: D17.1 (K), D19.1 (K), D21.1 (K), D23.1 (K), D25.1 (K), D27.1 (K), D29.1 (K), D95.1 (K), D97.1 (K); also elsewhere on the board
ROW3: D18.1 (K), D20.1 (K), D22.1 (K), D24.1 (K), D26.1 (K), D28.1 (K), D30.1 (K), D96.1 (K); also elsewhere on the board
ROW4: D35.1 (K), D37.1 (K), D39.1 (K), D41.1 (K), D43.1 (K), D45.1 (K), D47.1 (K), D99.1 (K), D101.1 (K); also elsewhere on the board
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

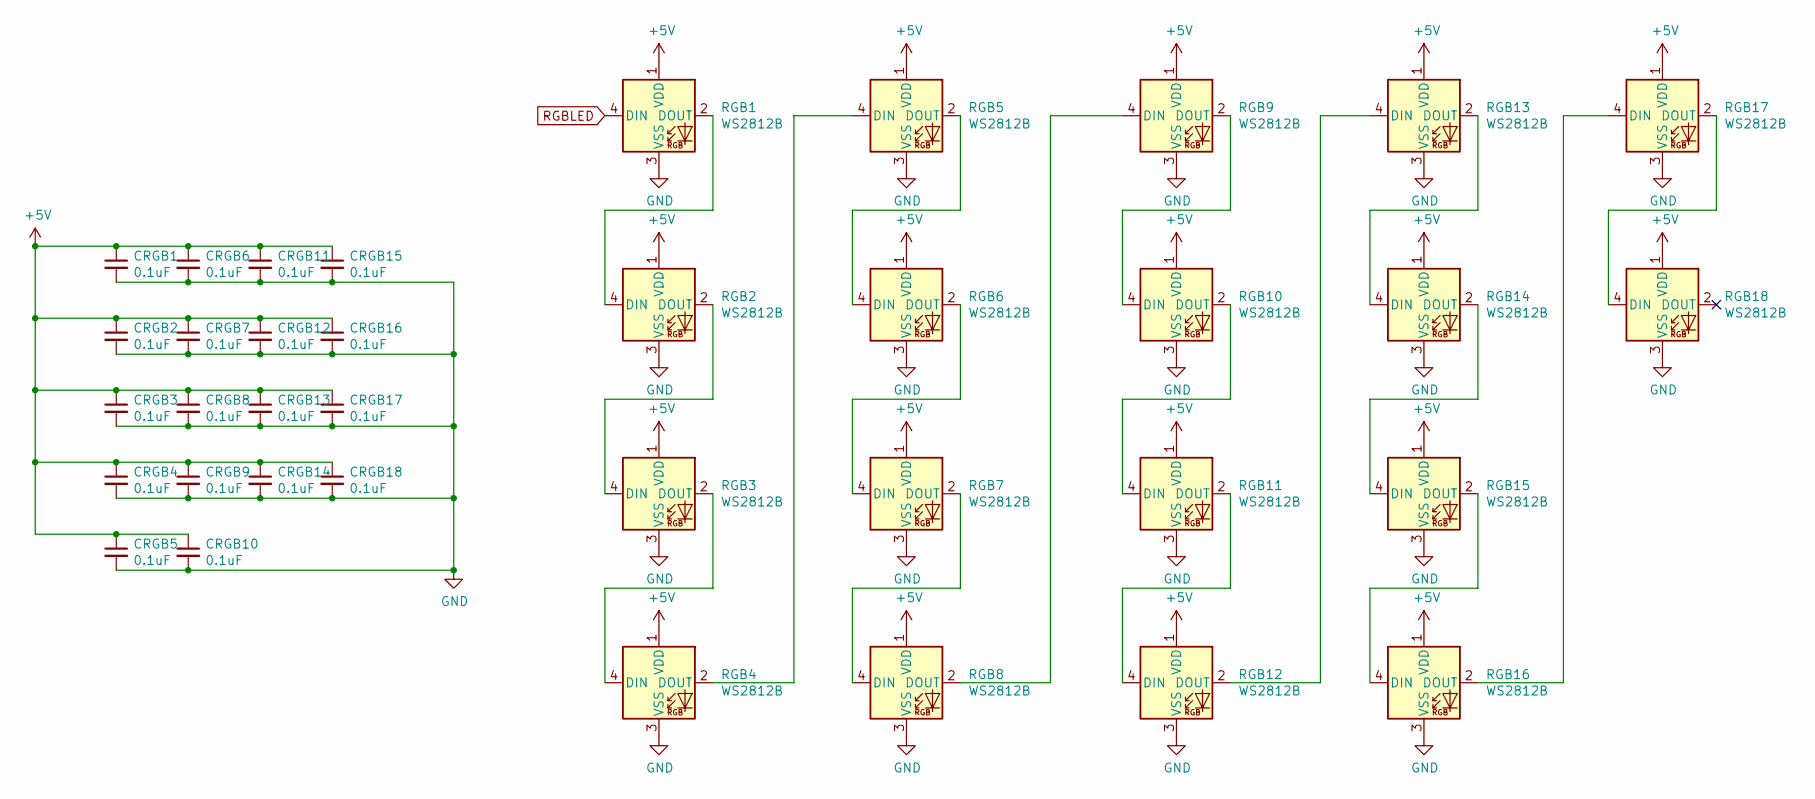
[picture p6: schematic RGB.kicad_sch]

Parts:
CRGB1, CRGB2, CRGB3, CRGB4, CRGB5, CRGB6, CRGB7, CRGB8, CRGB9, CRGB10, CRGB11, CRGB12, CRGB13, CRGB14, CRGB15, CRGB16, CRGB17, CRGB18: 0.1uF; C_0603
RGB1, RGB2, RGB3, RGB4, RGB5, RGB6, RGB7, RGB8, RGB9, RGB10, RGB11, RGB12, RGB13, RGB14, RGB15, RGB16, RGB17, RGB18: WS2812B; LED_WS2812B_PLCC4_5.0x5.0mm_P3.2mm

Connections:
+5V: CRGB1.1, CRGB2.1, CRGB3.1, CRGB4.1, CRGB5.1, CRGB6.1, CRGB7.1, CRGB8.1, CRGB9.1, CRGB10.1, CRGB11.1, CRGB12.1, CRGB13.1, CRGB14.1, CRGB15.1, CRGB16.1, CRGB17.1, CRGB18.1, RGB1.1 (VDD), RGB2.1 (VDD), RGB3.1 (VDD), RGB4.1 (VDD), RGB5.1 (VDD), RGB6.1 (VDD), RGB7.1 (VDD), RGB8.1 (VDD), RGB9.1 (VDD), RGB10.1 (VDD), RGB11.1 (VDD), RGB12.1 (VDD), RGB13.1 (VDD), RGB14.1 (VDD), RGB15.1 (VDD), RGB16.1 (VDD), RGB17.1 (VDD), RGB18.1 (VDD); also elsewhere on the board
GND: CRGB1.2, CRGB2.2, CRGB3.2, CRGB4.2, CRGB5.2, CRGB6.2, CRGB7.2, CRGB8.2, CRGB9.2, CRGB10.2, CRGB11.2, CRGB12.2, CRGB13.2, CRGB14.2, CRGB15.2, CRGB16.2, CRGB17.2, CRGB18.2, RGB1.3 (VSS), RGB2.3 (VSS), RGB3.3 (VSS), RGB4.3 (VSS), RGB5.3 (VSS), RGB6.3 (VSS), RGB7.3 (VSS), RGB8.3 (VSS), RGB9.3 (VSS), RGB10.3 (VSS), RGB11.3 (VSS), RGB12.3 (VSS), RGB13.3 (VSS), RGB14.3 (VSS), RGB15.3 (VSS), RGB16.3 (VSS), RGB17.3 (VSS), RGB18.3 (VSS); also elsewhere on the board
unnamed: RGB1.2 (DOUT), RGB2.4 (DIN)
unnamed: RGB2.2 (DOUT), RGB3.4 (DIN)
unnamed: RGB3.2 (DOUT), RGB4.4 (DIN)
unnamed: RGB4.2 (DOUT), RGB5.4 (DIN)
unnamed: RGB5.2 (DOUT), RGB6.4 (DIN)
unnamed: RGB6.2 (DOUT), RGB7.4 (DIN)
unnamed: RGB7.2 (DOUT), RGB8.4 (DIN)
unnamed: RGB8.2 (DOUT), RGB9.4 (DIN)
unnamed: RGB10.2 (DOUT), RGB11.4 (DIN)
unnamed: RGB9.2 (DOUT), RGB10.4 (DIN)
unnamed: RGB11.2 (DOUT), RGB12.4 (DIN)
unnamed: RGB12.2 (DOUT), RGB13.4 (DIN)
unnamed: RGB13.2 (DOUT), RGB14.4 (DIN)
unnamed: RGB14.2 (DOUT), RGB15.4 (DIN)
unnamed: RGB15.2 (DOUT), RGB16.4 (DIN)
unnamed: RGB16.2 (DOUT), RGB17.4 (DIN)
unnamed: RGB17.2 (DOUT), RGB18.4 (DIN)
RGBLED: RGB1.4 (DIN); also elsewhere on the board

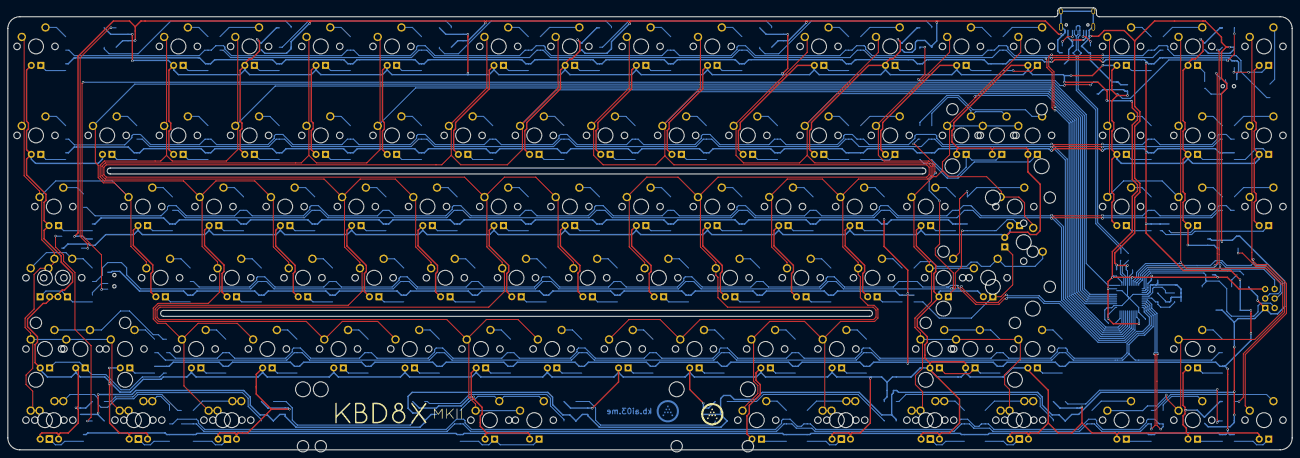
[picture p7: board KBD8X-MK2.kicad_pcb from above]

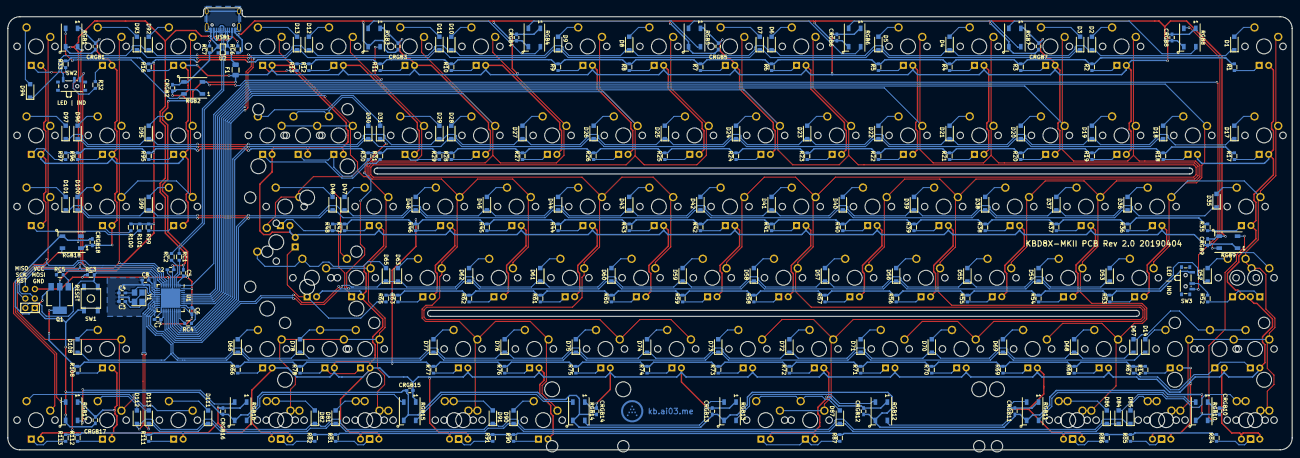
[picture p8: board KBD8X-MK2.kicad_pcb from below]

Board: 2 copper layers, 343.7 x 118.3 mm, 347 parts (242 on the bottom side), 240 nets.

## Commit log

2021-12-30 Repository cleanup
    [DXP_1921_1.csv.csv, DXP_1921_1.place.csv.csv, KBD8XMK2-BOM-2.place.csv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]
2021-12-31 Convert project to KiCad 6 format
    [KBD8X-MK2.kicad_pcb, KBD8X-MK2.kicad_sch, RGB.kicad_sch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]
2021-12-31 Added JLCPCB production files
    [BOM-KBD8X-MK2.csv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]
2022-01-08 Remove old Kicad project files
    [KBD8X-MK2.sch, RGB.sch, matrix.sch]
2022-01-08 Cleanup project
    [BOM-KBD8X-MK2.csv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]
2022-01-08 Update footprints and 3D shapes
    [KBD8X-MK2.kicad_pcb, RGB.kicad_sch]
2022-01-09 Made the project portable
    [BOM-KBD8X-MK2.csv, KBD8X-MK2.kicad_pcb, KBD8X-MK2.kicad_sch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]
2022-01-09 Added original R2.0 Gerber files
2022-01-09 Updated SOT-223-3_TabPin2 & SW_SPDT_PCM12 rotation angle
    [KBD8XMK2-R2.0-CPL.csv, POS-KBD8X-MK2.csv]
2022-01-09 Renamed Gerber file
2022-01-09 Added alternative part numbers
    [KBD8XMK2-R2.0-BOM_alternative.csv, KBD8XMK2-R2.0-BOM_to_test.csv]
2022-01-10 Fixed an issue with footprint library file
2022-01-13 Update part numbers
    [KBD8XMK2-R2.0-BOM.csv, KBD8XMK2-R2.0-BOM_alternative.csv, KBD8XMK2-R2.0-BOM_to_test.csv]
2022-01-16 Rearrenged schematics items
    [KBD8X-MK2.kicad_pcb, KBD8X-MK2.kicad_sch, RGB.kicad_sch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]
2022-01-16 Updated KBD8X_MK2_Switches schematic library
2022-01-16 Updated symbols used in the schematics
    [KBD8X-MK2.kicad_pcb, KBD8X-MK2.kicad_sch, matrix.kicad_sch]
2022-01-16 Removed unnecessary footprints
2022-01-16 Updated JLCPCB parts inventory
    [KBD8X-MK2.kicad_pcb]
2022-01-16 Added missing footprint
2022-01-16 Minor updates
    [matrix.kicad_sch]
2022-01-17 Updated footprints and schematic symbols
